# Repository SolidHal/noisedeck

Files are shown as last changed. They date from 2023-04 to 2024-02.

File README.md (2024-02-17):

# noisedeck

a cyberdeck for dealing in noise

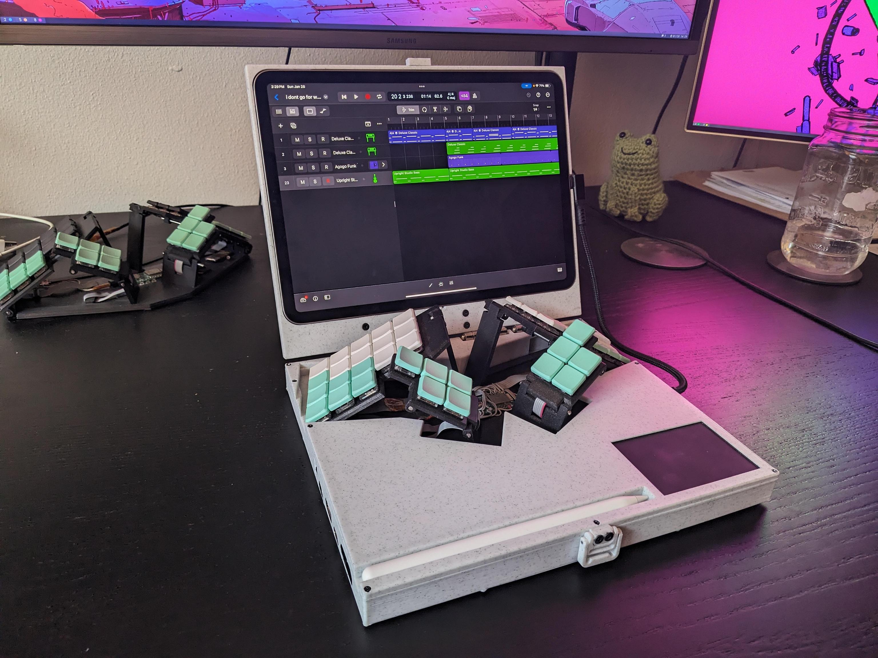
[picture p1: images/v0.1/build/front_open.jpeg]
front_open


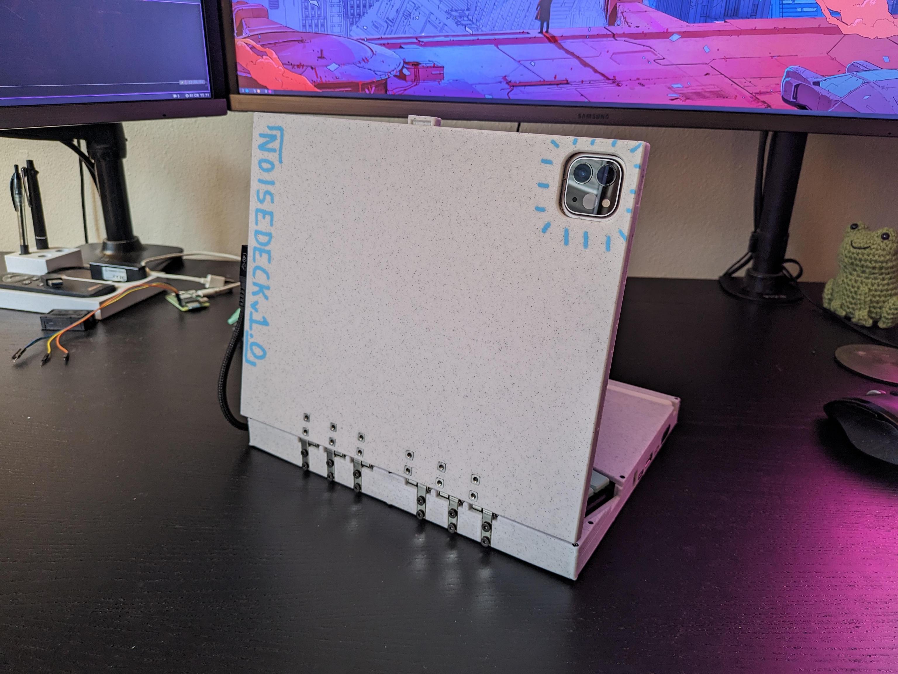
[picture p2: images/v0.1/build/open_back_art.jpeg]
back_art


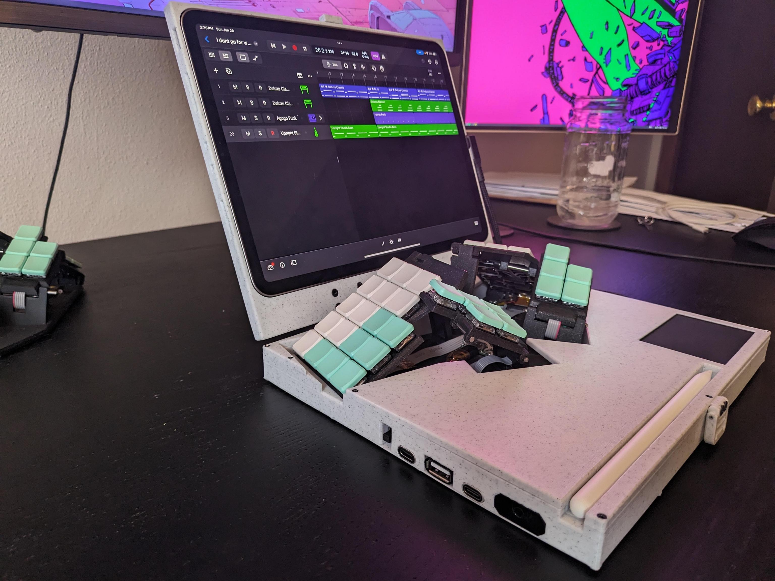
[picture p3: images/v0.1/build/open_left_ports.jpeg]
ports


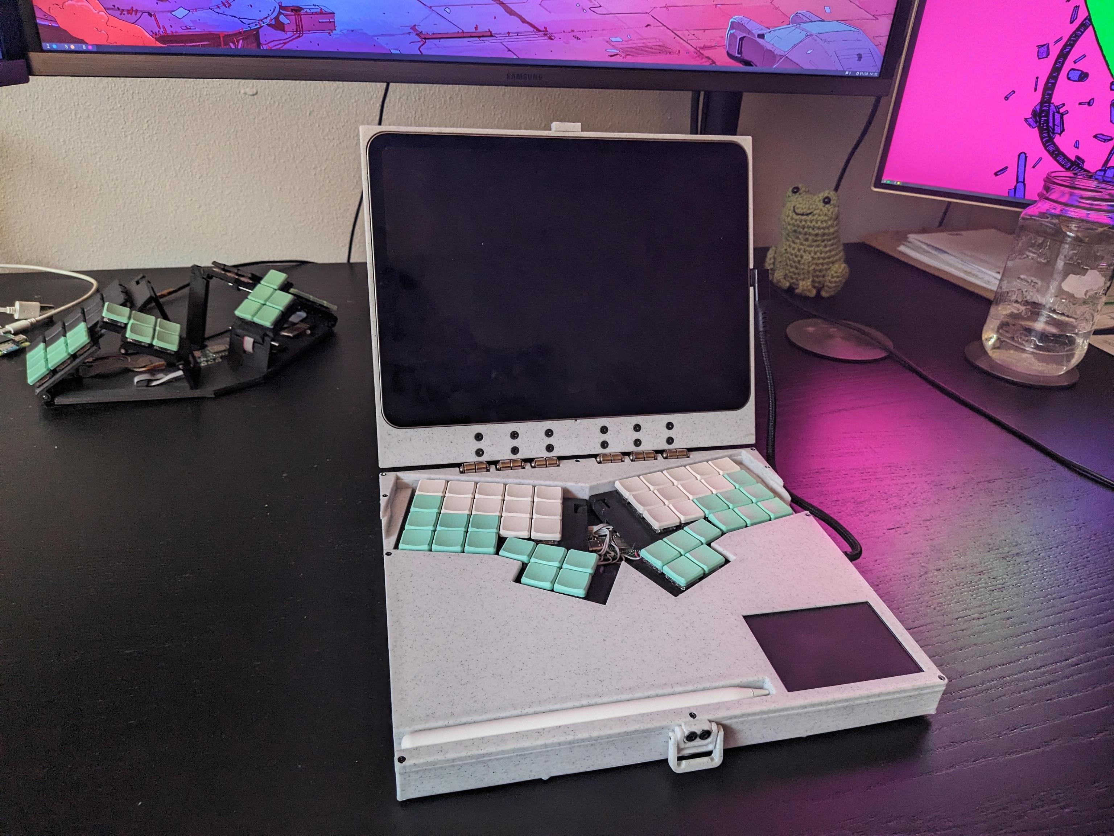
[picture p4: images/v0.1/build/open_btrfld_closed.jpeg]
btrfld_folded


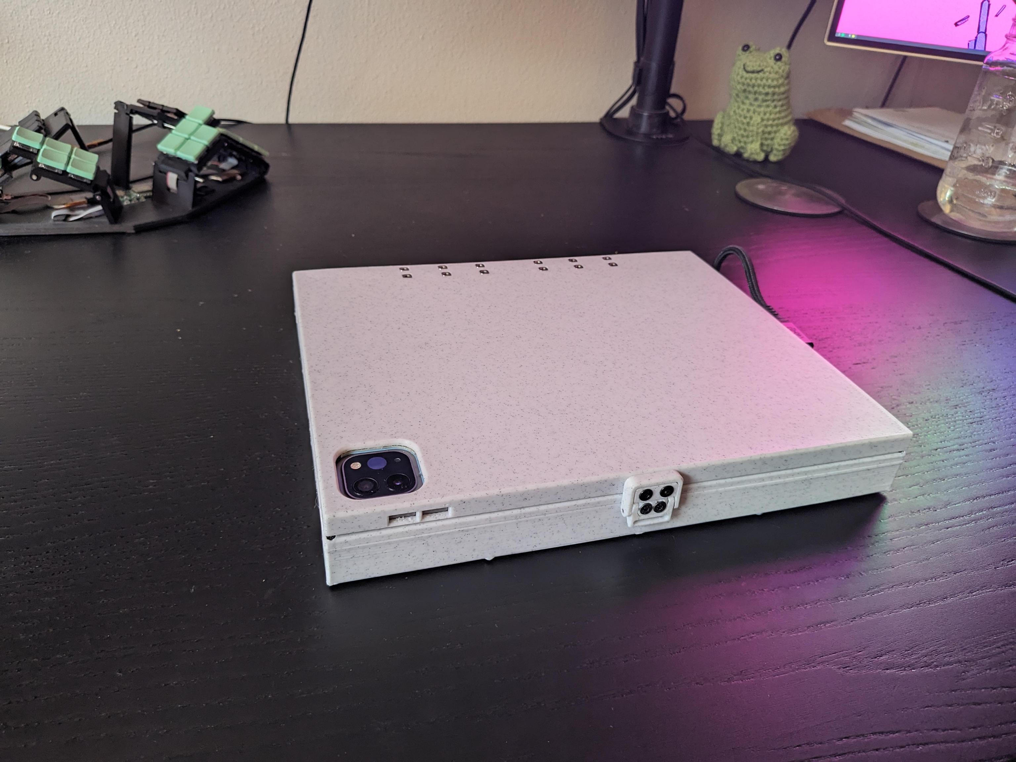
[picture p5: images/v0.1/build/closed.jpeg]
closed


## features
- btrfld keyboard
- trackpad
- headphone jack
- mic jack
- 1x usb c data port
- 1x usb c charge port
- 1x usb a port
- ipad: magnetically mounted
- ipad pencil and charging cradle
- rpi zero 2 w + 5000mah battery

future:
- extra keys in topcase for common hotkeys(?)
- choc key one octave keyboard in topcase(?)
- pitch joystick/wheel that snaps back to the center

the rpi zero 2 w is ran so its usb is in gadget mode, so it tells the ipad it is an ethernet device.
with this you can setup a local network and ssh directly from the ipad to the rpi without using wifi
this leaves the wifi chipset useful for other things

## Size constraints

btrfld:
- 129mm deep
- 215mm wide

## parts
hinges:
https://www.amazon.com/gp/product/B0BFWNJMCY/

hinge fasteners:
M3x8 countersunk fasteners: https://www.amazon.com/HanTof-Countersunk-Machine-Wrenches-Threaded/dp/B0B9HWVV61
M3x10 countersunk fasteners
M3 threaded, DIN 562 flat square nuts: https://www.amazon.com/M3nS-Printers-Stainless-Conform-Quantity/dp/B0BD2N9KTV

power switches:
https://www.amazon.com/dp/B075RC6TFB

apple pencil charging cradle:
https://www.amazon.com/Paiholy-Compatible-Generation-Lightweight-Convenient/dp/B0BMB7362T

midcase fasteners (plastic to plastic):
m2x5 and m2x6 tapered flat head self taping screws

cheap ipad magnetic folio case

btrfld keyboard: https://github.com/SolidHal/btrfld

usbc to 3x usbc (2 data, one power): https://www.amazon.com/gp/product/B09PFR2J82

usbc to 4x usbA : https://www.amazon.com/dp/B09N36LZSQ

usbA dac: https://www.amazon.com/dp/B01DLY3IW8

usbc right angle extension: https://www.amazon.com/dp/B0B71BZ4YF

rpi zero 2 w

5000mah battery

pcb usb hub https://www.amazon.com/dp/B09FX4QN4J

used to get a power only usbc port for charging the rpi battery: https://www.amazon.com/dp/B07VBV1PY5

## Notes

dac must have a power switch, otherwise the ipad will always use it by default and never allow usage of the speakers

TODO:

- holes in midcase/topcase and lid for latch(?)

- extra keys in topcase for common hotkeys(?)
- choc key one octave keyboard in topcase(?)

## Assembly notes

case:
- use 52 gauge drill bit to clean out midcase holes for the m2 screws
- use 46 gauge drill bit to clean out topcase holes for the m2 screws
- use chamfer bit on bottomcase holes screws sit flush
- glue eyeglass nosepads to bottomcase for feet
- hinges need to be filed/ground shorter on the side that would otherwise stick out through the bottom case
- cleaning out the hinge holes in the ipad enclosure is annoying. Recommend using a 46 gauge drill bit
- tear down the ipad folio case to just the parts required to hold the magnets in place. lets call this the "case core"
  - attach a thin film to the side of the case core that magnetizes to the ipad
  - superglue the case core into the ipad enclosure so that the ipad is held into the ipad enclosure magnetically

- the 5000mah battery pack fits nicely under the dac.

wiring:

The wiring is a bit messy, but it works and all fits with plenty of space:

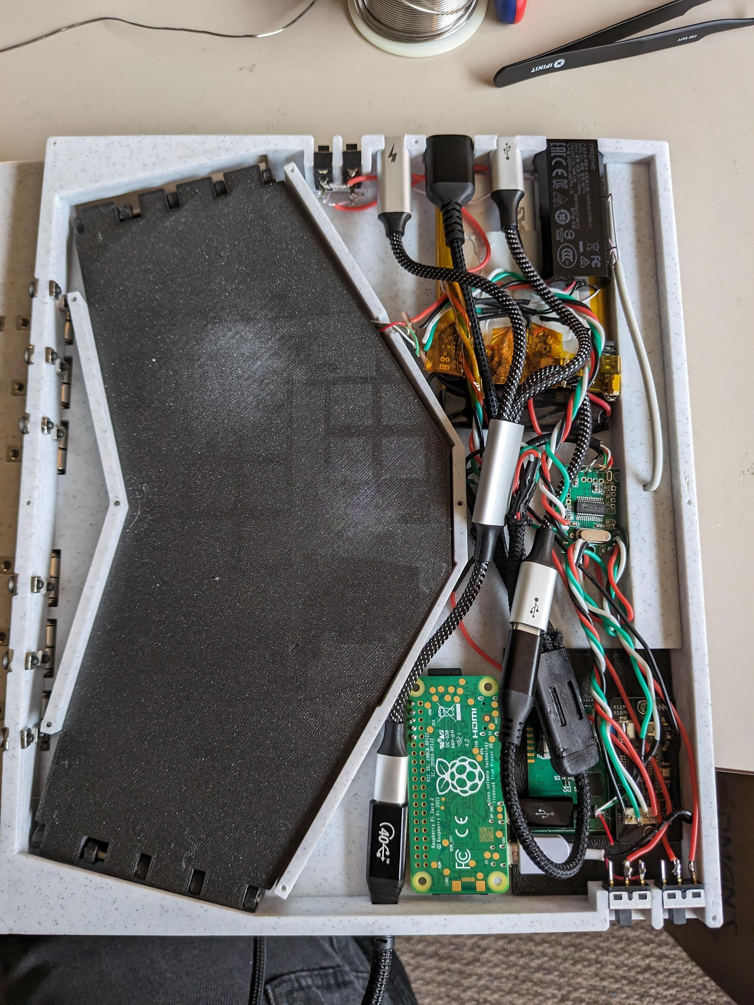
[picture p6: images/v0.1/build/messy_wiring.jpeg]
wiring


ipad -> extension -> usbc/usbc 3 way splitter -> one usbc charging port, one usbc data port, and the usbc to usbA splitter

usbA splitter:
- port 1:
  - data and ground to headphone port dac
  - power to two switches on the left side of the noisedeck. One switch to the dac, other to pencil charger. Only use one of these at a time.
- port 2:
  - data only to rpi zero 2w data port. Power to nowhere
- port 3:
  - to pcb usb hub:
    - port 3a:
      - to btrfld
    - port 3b:
      - to trackpad
- port 4:
  - glued into the left side of the noisedeck, externally accessible usbA port

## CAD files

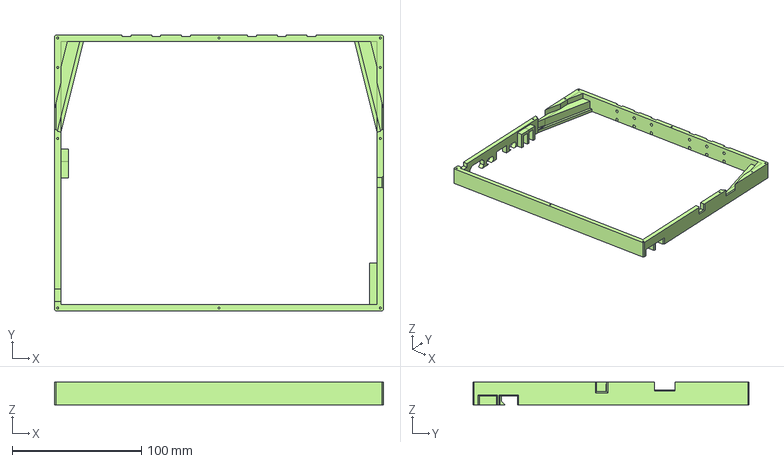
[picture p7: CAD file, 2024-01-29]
cad/case_assembly.FCStd
254.6 x 213.9 x 17.7 mm

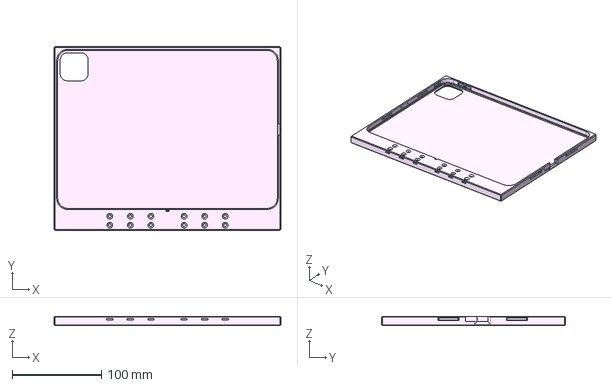
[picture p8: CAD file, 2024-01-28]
cad/lcd_assembly.FCStd
254.6 x 206.0 x 10.5 mm

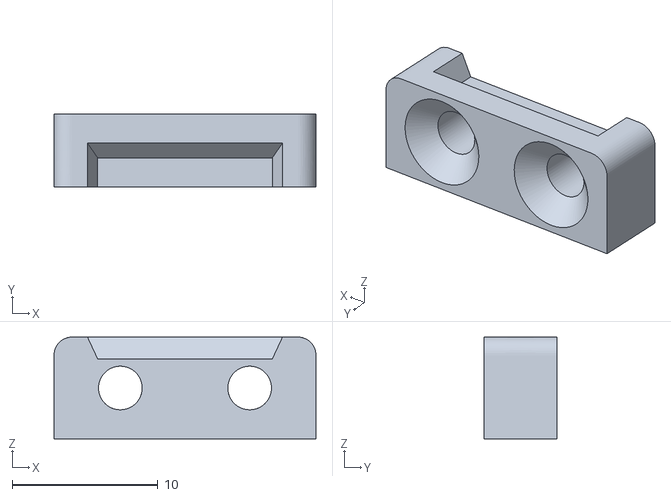
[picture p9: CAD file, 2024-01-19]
cad/latch/draw_latch_block.stl
18.0 x 5.00 x 7.00

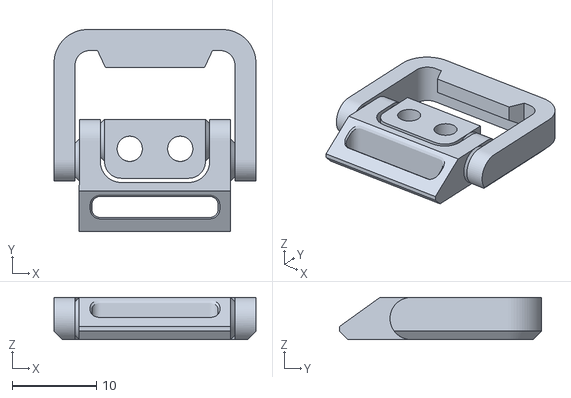
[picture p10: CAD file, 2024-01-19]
cad/latch/draw_latch.stl
24.0 x 24.0 x 5.00

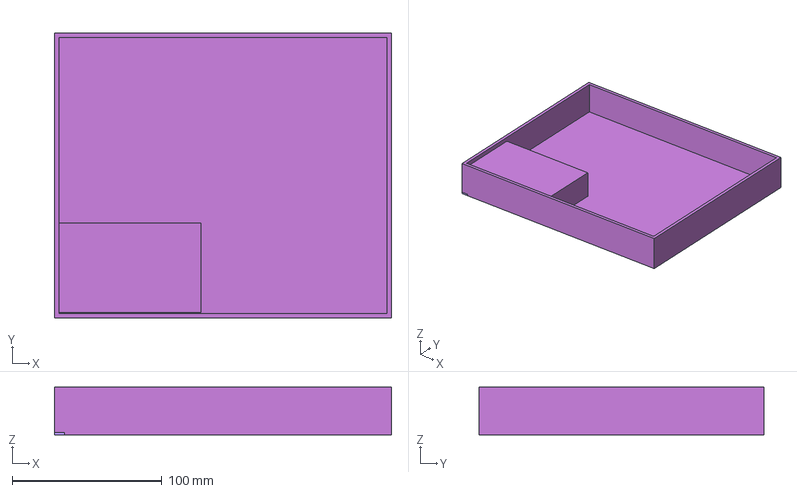
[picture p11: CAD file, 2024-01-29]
cad/noisedeck.FCStd
225.0 x 190.0 x 32.0 mm
general_layout
hinge_half

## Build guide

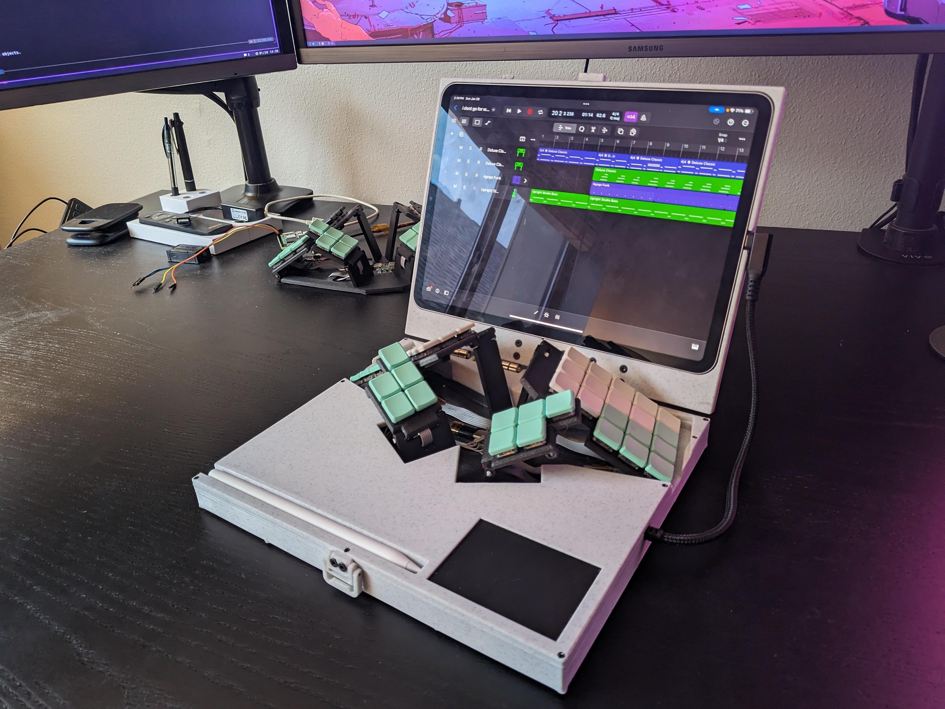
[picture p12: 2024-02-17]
images/v0.1/build/front_open_right.jpeg

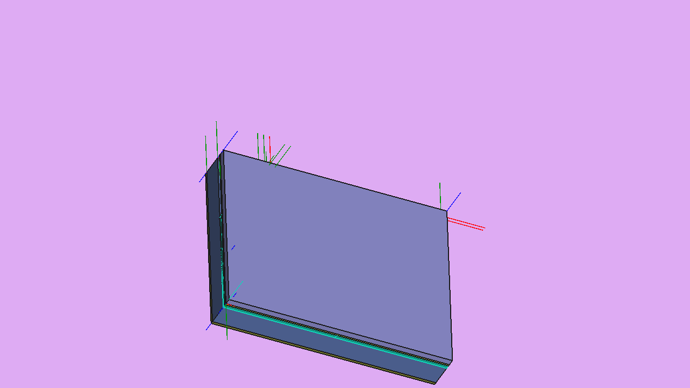
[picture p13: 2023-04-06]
demos/early_assembly/open.gif

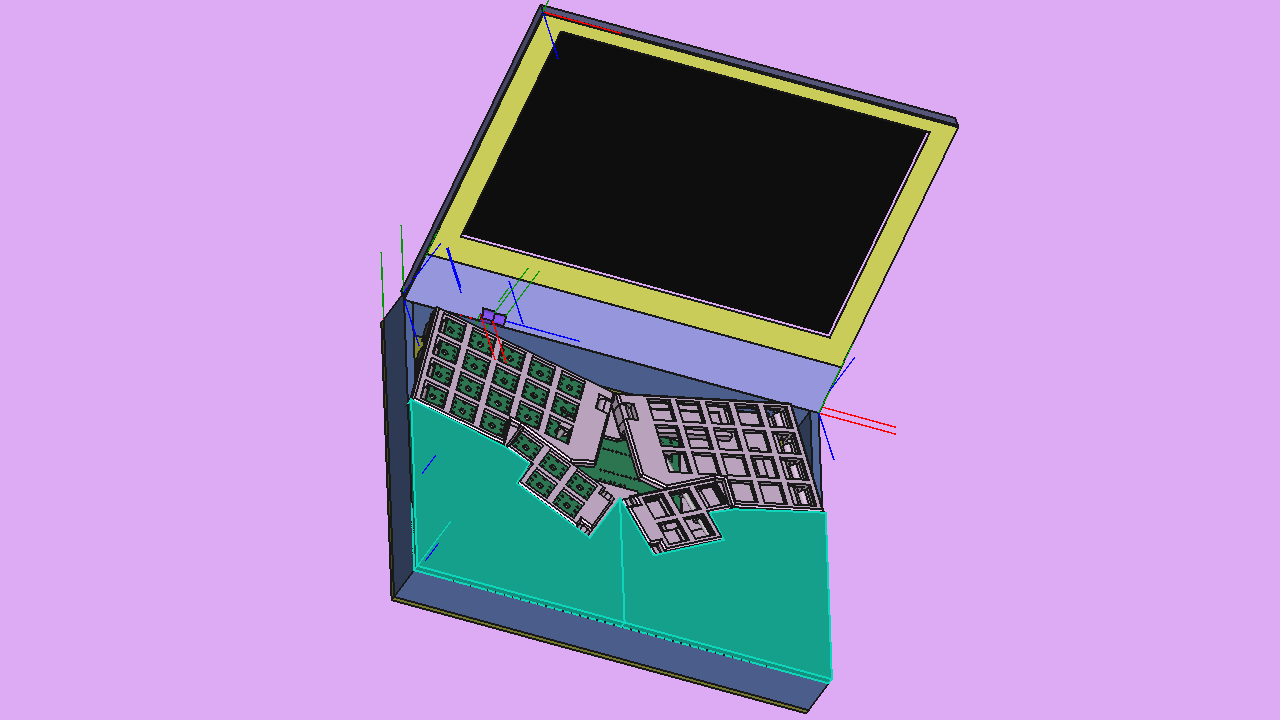
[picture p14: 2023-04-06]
demos/early_assembly/open_keyboard.gif

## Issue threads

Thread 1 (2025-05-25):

Project status and future

tomoakley, 2025-05-25:
Hi Evalyn,
I love the look of this project. I'm currently 3D printing your btrfld keyboard to solder together for use with my iPad Pro (12.9 inch 2024 model). I have some questions about noisedeck:
- do you use it regularly?
- do you plan on doing further work on it?
- what's the purpose of the raspberry pi and other hardware?

I would love to be able to adapt this to fit my iPad. I'm not a CAD engineer unfortunately so don't have much knowledge on how to do that. Can you give any pointers? Also, it won't fit on my printer (Ender 3 Pro). What printer did you use to print the parts?

Thanks ☺️

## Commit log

2023-03-25 initial sizing cad
    [emdeck.FCStd]
2023-03-28 initial model of the lcd assembly
    [emdeck.FCStd]
2023-04-05 split into multiple assemblies, bring in btrfld
    [case_assembly.FCStd, emdeck.FCStd, lcd_assembly.FCStd]
2023-04-06 fixup lcd position
    [case_assembly.FCStd, emdeck.FCStd, lcd_assembly.FCStd]
2023-04-06 test fit of hinges
    [case_assembly.FCStd, emdeck.FCStd, lcd_assembly.FCStd]
2023-04-06 correct lcd width, place lcd controller
    [case_assembly.FCStd, emdeck.FCStd, lcd_assembly.FCStd]
2023-04-07 poke cpu, cooler outside of midcase. Adjust topcase lower
    [case_assembly.FCStd, emdeck.FCStd]
2023-04-07 add btrfld supports to topcase_lower
    [case_assembly.FCStd, emdeck.FCStd]
2023-05-31 account for keys and keycaps
    [case_assembly.FCStd, emdeck.FCStd, lcd_assembly.FCStd]
2023-06-06 place batteries, use bottom case as heatsink
    [case_assembly.FCStd, emdeck.FCStd, lcd_assembly.FCStd]
2023-06-06 place voltage regulation, trackpad, cleanup lower topcase
    [case_assembly.FCStd, emdeck.FCStd]
2023-09-19 hinge work
    [emdeck.FCStd, lcd_assembly.FCStd]
2023-09-20 add upper topcase
    [case_assembly.FCStd, emdeck.FCStd, lcd_assembly.FCStd]
2023-09-20 finalize trackpad, volter converters, batteries
    [case_assembly.FCStd, emdeck.FCStd]
2023-09-20 update notes
    [case_assembly.FCStd, emdeck.FCStd]
2023-09-29 place all ports, start placing fasteners
    [case_assembly.FCStd, emdeck.FCStd, lcd_assembly.FCStd]
2023-09-29 chamfer all the edges
    [case_assembly.FCStd, emdeck.FCStd, lcd_assembly.FCStd]
2023-09-29 add fastener holes to lcd bezel
    [emdeck.FCStd, lcd_assembly.FCStd]
2023-09-29 place keys on btrfld
    [emdeck.FCStd]
2023-09-29 break up topcase into printable parts
    [case_assembly.FCStd, emdeck.FCStd]
2023-09-29 try out some colors, add ports to cpu board
    [case_assembly.FCStd, emdeck.FCStd, lcd_assembly.FCStd]
2023-10-03 corrections from first test print
    [case_assembly.FCStd, emdeck.FCStd, lcd_assembly.FCStd]
2023-11-26 corrections from second print test
    [case_assembly.FCStd, emdeck.FCStd, lcd_assembly.FCStd]
2023-11-26 added magnet holes, adjused led space
    [case_assembly.FCStd, emdeck.FCStd, lcd_assembly.FCStd]
2023-11-26 adjust btrfld supports
    [case_assembly.FCStd, emdeck.FCStd]
2023-11-26 adjust ethernet, audio, power port sizes
    [case_assembly.FCStd, emdeck.FCStd]
2023-11-26 make the cable run section of the lcd enclosure thicker
    [case_assembly.FCStd, emdeck.FCStd]
2023-11-30 adjust magnet positions
    [case_assembly.FCStd, emdeck.FCStd, lcd_assembly.FCStd]
2023-11-30 fixup magnets
    [emdeck.FCStd, lcd_assembly.FCStd]
2023-12-20 update TODOs
    [case_assembly.FCStd, emdeck.FCStd]
2023-12-20 base noisedeck off of existing cyberdeck project
    [emdeck.FCStd, noisedeck.FCStd]
2023-12-21 rough model of ipad keepout zones
    [lcd_assembly.FCStd]
2023-12-22 rough ipad enclosure
    [case_assembly.FCStd, lcd_assembly.FCStd]
2023-12-31 add room for ipad magnet sheet, add port/button cutouts
    [case_assembly.FCStd, lcd_assembly.FCStd, noisedeck.FCStd]
2023-12-31 hinges placed in midcase
    [case_assembly.FCStd, noisedeck.FCStd]
2024-01-02 attached ipad assembly to case
    [case_assembly.FCStd, lcd_assembly.FCStd, noisedeck.FCStd]
2024-01-02 set midcase size
    [case_assembly.FCStd, noisedeck.FCStd]
2024-01-02 correct btrfld placement
    [case_assembly.FCStd, noisedeck.FCStd]
2024-01-02 add midcase slots for tented btrfld
    [case_assembly.FCStd, noisedeck.FCStd]
2024-01-02 fixup upper topcase, midcase hinge placement
    [case_assembly.FCStd, noisedeck.FCStd]
2024-01-02 fix lower topcase
    [case_assembly.FCStd, noisedeck.FCStd]
2024-01-04 make ipad enclosure thicker
    [case_assembly.FCStd, lcd_assembly.FCStd, noisedeck.FCStd]
2024-01-04 fixup topcase supports
    [case_assembly.FCStd]
2024-01-06 add lip to ipad enclosure to better fit magnet case
    [case_assembly.FCStd, lcd_assembly.FCStd, noisedeck.FCStd]
2024-01-06 place left ports
    [case_assembly.FCStd, noisedeck.FCStd]
2024-01-06 finalize upper topcase
    [case_assembly.FCStd, noisedeck.FCStd]
2024-01-07 add ipad pencil slot and charger
    [case_assembly.FCStd, noisedeck.FCStd]
2024-01-07 begin midcase btrfld spacers
    [case_assembly.FCStd, noisedeck.FCStd]
2024-01-08 finish btrfld midcase spacers
    [case_assembly.FCStd, noisedeck.FCStd]
2024-01-08 add main usbc dock port
    [case_assembly.FCStd, noisedeck.FCStd]
2024-01-08 place midcase screwholes
    [case_assembly.FCStd, noisedeck.FCStd]
2024-01-11 first full test
    [case_assembly.FCStd, noisedeck.FCStd]
2024-01-14 simplify main usbc cable port hole
    [case_assembly.FCStd, noisedeck.FCStd]
2024-01-14 added more hinges to midcase
    [case_assembly.FCStd, noisedeck.FCStd]
2024-01-14 lcd_assembly add more hinges
    [lcd_assembly.FCStd, noisedeck.FCStd]
2024-01-14 increase ipad enclosure hinge hole depth
2024-01-14 fixup port sizes
    [case_assembly.FCStd, lcd_assembly.FCStd, noisedeck.FCStd]
2024-01-14 add dac power switch
    [case_assembly.FCStd, noisedeck.FCStd]
2024-01-15 combine topcase supports with topcase parts.
    add screwholes for topcase
    supports and bottomcase
    [case_assembly.FCStd, noisedeck.FCStd]
2024-01-15 adjust topcase upper hinge gap spacing
    [case_assembly.FCStd, noisedeck.FCStd]
2024-01-16 increase dac switch slot height, add another screw hole to bottom case
    [case_assembly.FCStd, noisedeck.FCStd]
2024-01-19 add latch stls
    [draw_latch.stl, draw_latch_block.stl]
2024-01-28 lid square nut hole slightly deeper, holes for hinge in lid slightly wider
    [case_assembly.FCStd, lcd_assembly.FCStd, noisedeck.FCStd]
2024-01-28 make port holes a bit bigger
    [case_assembly.FCStd, noisedeck.FCStd]
2024-01-28 put small chamfer in lid for right angle usbc cable
    [lcd_assembly.FCStd, noisedeck.FCStd]
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2024-01-29 fixup midcase switch slot
    [case_assembly.FCStd, noisedeck.FCStd]
2024-01-29 add more slots for switches in the midcase
    [case_assembly.FCStd, noisedeck.FCStd]
